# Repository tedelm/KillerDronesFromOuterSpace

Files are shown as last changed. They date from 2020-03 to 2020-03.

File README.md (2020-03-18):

# KillerDronesFromOuterSpace
</br>
Have you ever wanted to shot your friends and enemies with Nerf darts launched from a drone? 
</br>
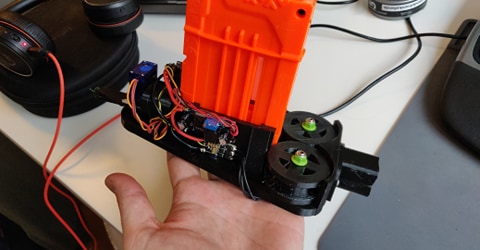
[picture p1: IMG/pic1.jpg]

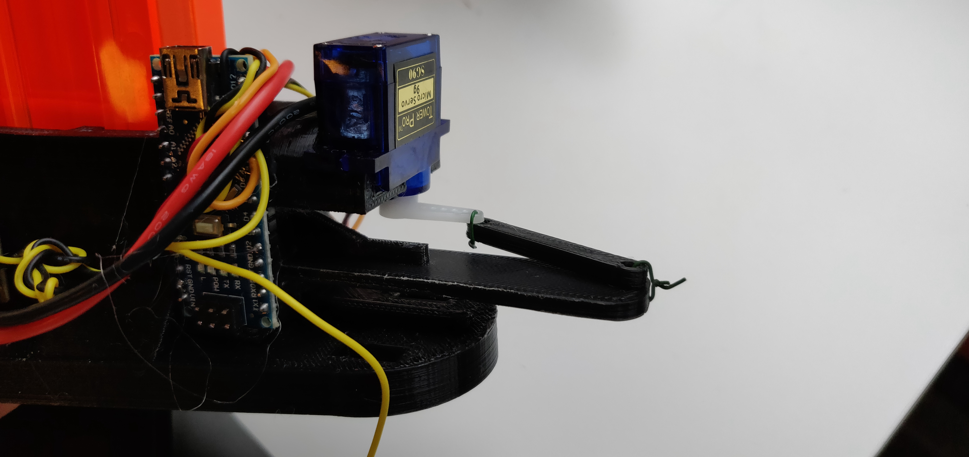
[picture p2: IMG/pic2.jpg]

</br>
</br>

# Make
Needed
- [ ]  Download KillerDroneFromOuterSpace files (Arduino and STL)
- [ ]  Download BLHeli Suite
- [ ]  Print STL files
- [ ]  1 x Nerf Mag.
- [ ]  2 x Blheli_s or Blheli_32 Esc (25-30amp)
- [ ]  2 x Brushless motor, like 2207 (6s 1600kv or 4s 2400kv)
- [ ]  1 x Arduino Nano
- [ ]  1 x SG90 Servo (9g servo)
- [ ]  1 x 5v BUCK/BEC (min 25v stepdown) like LM2596
- [ ]  1 x 4s/6s Lipo
- [ ]  3cm Thin (~1mm) Garden wire (for pulley/servo)
- [ ]  Super Glue
- [ ]  Some thin (~24AWG) and some thick(er) (~14) gauge wire
- [ ]  Some M3x6mm for motors (8pcs) and pipe (2pcs)
- [ ]  HotGlue Gun

# Flash BLHELI_S ESC´s
Download: <a href='http://www.mediafire.com/file/23jnmpa0kiqry1k/BLHeliSuite16714902.zip/file'>Windows BLHELI_S Suite</a></br>
or browse for your version: <a href='https://www.mediafire.com/folder/dx6kfaasyo24l/BLHeliSuite'>All versions</a></br>
</br>
1. Connect Arduino to Computer</br>
2. Start BLHeli Suite</br>
3. Options -> "Expert Mode"</br>
4. Make Interfaces</br>
5. Select "Port" eg. COM5</br>
6. Click Arduino BLHeli BootLoader</br>
7. After the arduino is flashed with blheli bootloader, disconnect the Arduino from computer.</br>
8. Select "ATMEL / SILABS interface" as described, its usually "SILABS BLHELI Bootloader (USB/COM)"</br>
9. Solder GND and Signal from ESC to Arduino GND and D2 and solder vbat+ and vbat- to ESC</br>
10. Connect Arduino to Computer and start BLHeli Suite, click "Connect"</br>
11. Connect Lipo (VBAT+/VBAT-)</br>
12. Click "Flash BLHeli", select newest FW (Default)</br>
13. Repeat steps 1-12 for both esc´s.</br>
</br>

# Flash BLHELI_32 ESC´s
Download <a href='http://www.mediafire.com/file/as2n6rkbah053zp/BLHeliSuite32_32711.zip/file'>Windows BLHELI_32 Suite</a></br>
or browse for your version: <a href='https://www.mediafire.com/folder/dx6kfaasyo24l/BLHeliSuite'>All versions</a></br>
1. Connect Arduino to Computer</br>
2. Start BLHeli Suite</br>
3. Options -> "Expert Mode"</br>
4. Make Interfaces</br>
5. Select "Port" eg. COM5</br>
6. Click Arduino BLHeli BootLoader</br>
7. After the arduino is flashed with blheli bootloader, disconnect the Arduino from computer.</br>
8. Select "ATMEL / SILABS interface" as described, its usually "SILABS BLHELI Bootloader (USB/COM)"</br>
9. Solder GND and Signal from ESC to Arduino GND and D2 and solder vbat+ and vbat- to ESC</br>
10. Connect Arduino to Computer and start BLHeli Suite, click "Connect"</br>
11. Connect Lipo (VBAT+/VBAT-)</br>
12. Click "Flash BLHeli", select newest FW (Default)</br>
13. Repeat steps 1-12 for both esc´s.</br>
</br>

# Flash Arduino
1. Download and istall Arduino IDE <a href='https://www.arduino.cc/en/main/software'>Link</a></br>
2. Open Arduino IDE and open the sketch "KillerDroneFromOuterSpace.ino" </br>
3. Select correct Arduino under </br>
    Tools->Board = Arduino nano </br>
    Tools->Processor = ATMega328p (Old bootloader)</br>
    Tools->Port = COMx</br>
4. Press "Upload"    </br>

# Connect to Arduino (schematic)
Schematic:</br>
    ESC #1 (signal) -> Arduino pin: D9</br>
    ESC #1 (gnd, for signal) -> Arduino pin GND  </br>
    ESC #2 (signal) -> Arduino pin: D10</br>
    ESC #2 (gnd, for signal) -> Arduino pin GND</br>
    Servo (signal)  -> Arduino pin: D8</br>
    Servo (gnd)  -> 5v BUCK/BEC GND out</br>
    Servo (Vcc/+)  -> 5v BUCK/BEC Vcc/+ out</br>
    RevoltOSD TX4 (Pin Toggle) -> Arduino pin: A7</br>
    5v Buck/BEC (IN GND/VCC) -> VBAT GND/VCC</br>

# Build
1. Test-fit everything</br>
2. File the parts that not fit perfect </br>
3. Super glue "Guider" to the "Bottom" </br>
4. Screw or glue the "pipe" to the "Bottom"
5. Test-fit the servo, see to it that the arm can move freely, connect slider and slider_arm to the servo with garden wire.
6. Super glue the servo in place.
7. Hotglue the electonics to the side :D

```code
```

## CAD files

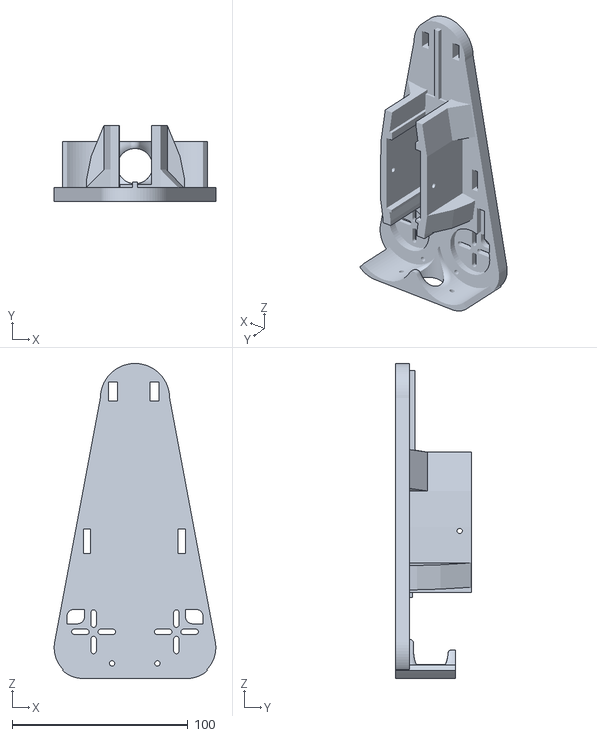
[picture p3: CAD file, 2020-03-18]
STL/bottom_v2.1.stl
91.9 x 43.0 x 179.0

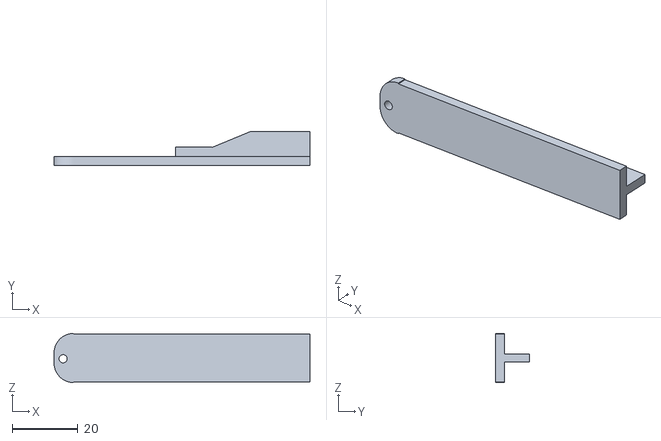
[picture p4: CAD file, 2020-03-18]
STL/slider2.1.stl
78.0 x 10.5 x 15.0

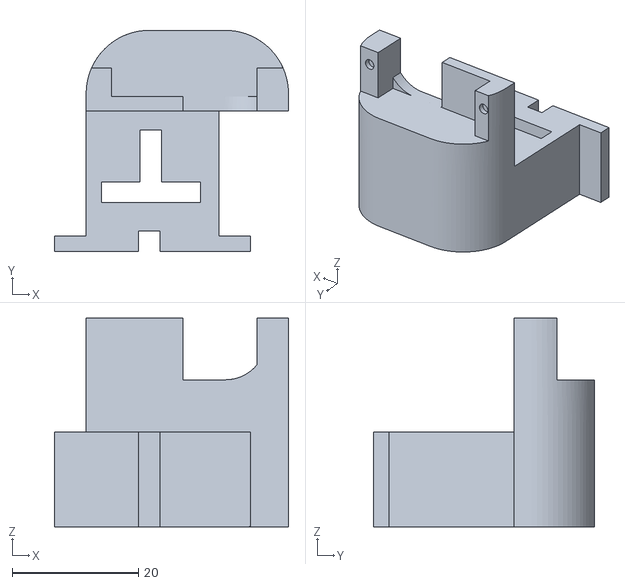
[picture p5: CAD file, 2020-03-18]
STL/Guider.stl
37.0 x 35.0 x 33.0

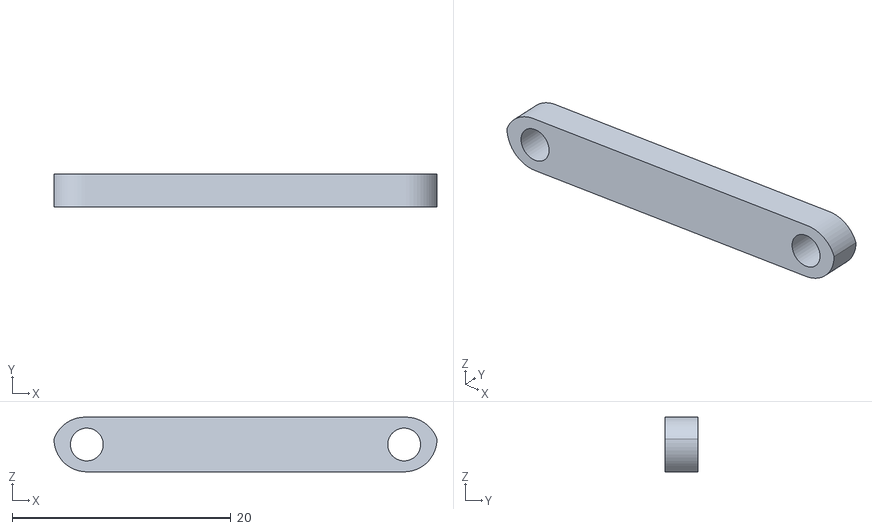
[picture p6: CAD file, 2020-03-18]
STL/slider_arm.stl
35.0 x 3.00 x 5.00

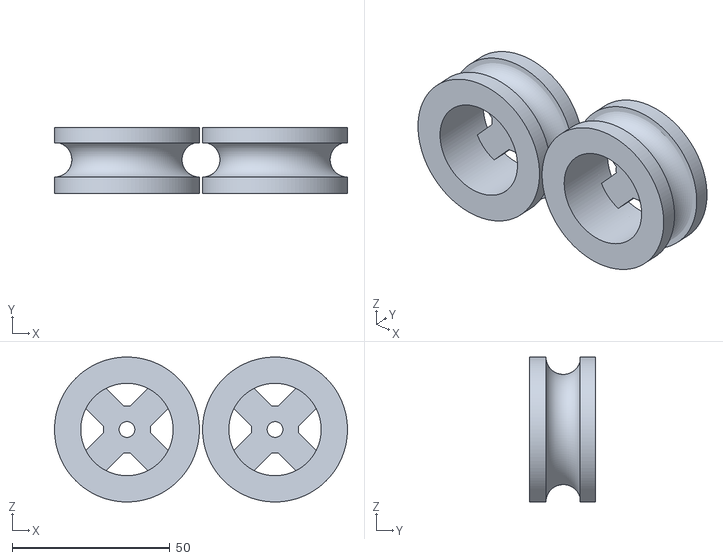
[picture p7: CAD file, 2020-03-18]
STL/driver_v2.stl
93.0 x 21.0 x 46.0

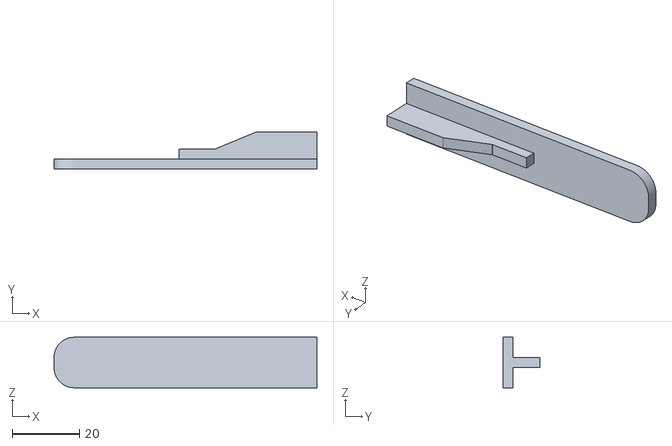
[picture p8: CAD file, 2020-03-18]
STL/slider.stl
78.0 x 11.0 x 15.0

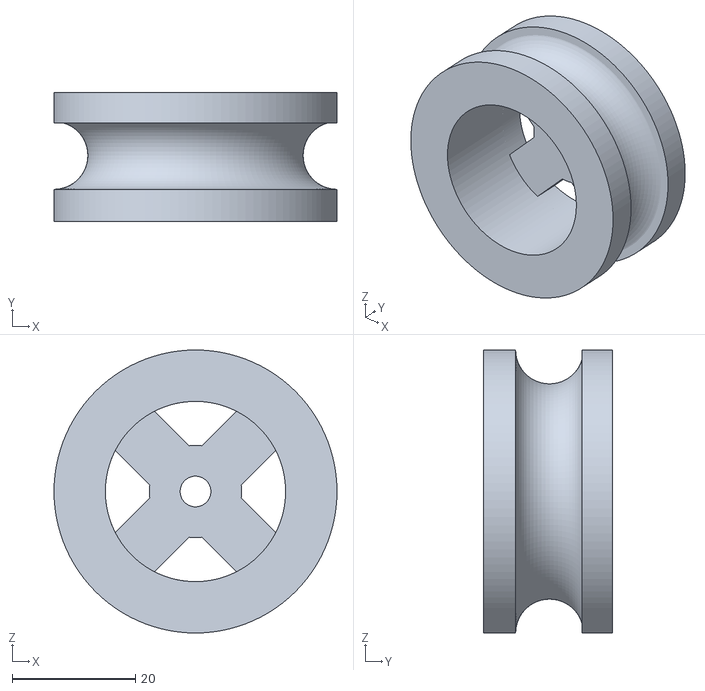
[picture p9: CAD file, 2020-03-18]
STL/driver_v2_1pcs.stl
46.0 x 21.0 x 46.0

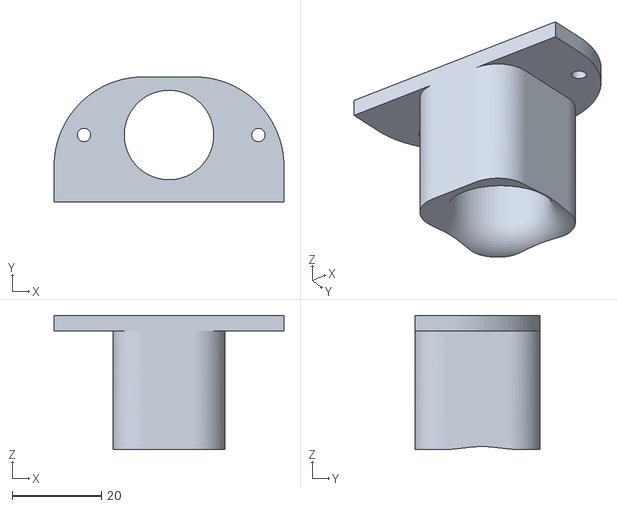
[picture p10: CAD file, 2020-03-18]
STL/pipe.stl
51.4 x 28.0 x 30.0

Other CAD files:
STL/bottom_v2.stl

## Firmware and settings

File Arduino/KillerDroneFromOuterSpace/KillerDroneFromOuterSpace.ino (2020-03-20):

//https://www.youtube.com/watch?time_continue=739&v=MvhqtOEihDg&feature=emb_title
//https://www.mediafire.com/folder/dx6kfaasyo24l/BLHeliSuite
//-> make interface -> Arduino BLHeli Bootloader


//Battery - > GND
//Trigger > D2
// Servo Signal (PULSE) > D9
// Servo Signal (PULSE) > D10

// Don't change the below setting 

#include <Servo.h>
Servo motor1;               //ESC1
Servo motor2;               //ESC2
Servo Feeder;               //Servo feeder
float motorMIN = 950;       //motor min, motors disabled
float motorMID = 1450;      //motor MID
float motorMAX = 1960;      //motor max
float MotorCMD = motorMIN;  //Command sent to esc
int motor1PIN = 9;          //Arduino PIN D9
int motor2PIN = 10;         //Arduino PIN D10
int TogglePIN = A7;          //A High/Low toggle pin on FC, RevoltOSD is TX4 3,3v. (1023/5)*3.3=675, so to be safe we set limit to 640
int TogglePINActive = 640;  //(1023/5)*3.3=675, so to be safe we set limit to 640
int FeederPin = 8;          //Servo
int TogglePINState = 0;     // variable to store the read value
int angle = 10;             //Servo angle
int ServoSteps = 25;             //Servo angle
int LastAction = 0;         //when button pressed
//

void setup() {
    Feeder.attach(FeederPin);           //Attach PIN
    motor1.attach(motor1PIN);           //Attach PIN
    motor2.attach(motor2PIN);           //Attach PIN
    Serial.begin(57600);                //Serial Monitor
    motor1.write(motorMIN);
    motor2.write(motorMIN);
    delay(5000);
}

void FeedDart(){
 // from 0 to 180 degrees
  for(angle = 10; angle < 180; angle = angle + ServoSteps){                                  
    Feeder.write(angle);               
    delay(5);                   
  } 
  // from 180 to 0 degrees
  for(angle = 180; angle > 10; angle = angle - ServoSteps){                                
    Feeder.write(angle);           
    delay(5);       
  } 
delay(250);
}

void EnableMotors(){

    if(LastAction == 0){
        //Ramp up motors MAX RPM
        for(MotorCMD = motorMIN; MotorCMD < motorMAX; MotorCMD = MotorCMD + 50){                                  
            Serial.println(MotorCMD);
            motor1.write(MotorCMD);
            motor2.write(MotorCMD);              
            delay(10);                   
        }

    }else{
        MotorCMD = motorMAX;
        Serial.println(MotorCMD);
        motor1.write(MotorCMD);
        motor2.write(MotorCMD);

    }
    
        MotorCMD = motorMAX;
        Serial.println(MotorCMD);
        motor1.write(MotorCMD);
        motor2.write(MotorCMD);
    LastAction = 1;
    
}

void DeactiveateMotors(){


        //Ramp down motors min RPM
        for(MotorCMD = motorMAX; MotorCMD > motorMIN; MotorCMD = MotorCMD - 10){                                  
            Serial.println(MotorCMD);
            motor1.write(MotorCMD);
            motor2.write(MotorCMD);
            delay(10);

            //Manual interrupt, check if button pressed while motors are spinning down
            ToggleState();

        }

    MotorCMD = motorMIN;        //Set motors MIN RPM
    Serial.println(MotorCMD);
    motor1.write(MotorCMD);
    motor2.write(MotorCMD);

    LastAction = 0;
}

void ToggleState(){
    
    TogglePINState = analogRead(TogglePIN);    //Read TogglePIN
    Serial.println(TogglePINState);
    
    if (TogglePINState > TogglePINActive){
        
        delay(50);
        TogglePINState = analogRead(TogglePIN);    //Read TogglePIN
        Serial.println(TogglePINState);
        //Doublecheck
        if (TogglePINState > TogglePINActive){

            //Check if motors already enabled
            if(LastAction == 1){
                FeedDart();     //Feed dart
            }else{
                EnableMotors(); //Start motors
                delay(25);     //sleep
                FeedDart();     //Feed dart
            }

            //Set last action to Enabled
            LastAction = 1;
        }
    
    }else{
      
      if(LastAction == 1){
        DeactiveateMotors(); //Start motors
        delay(25);          //sleep
      }
      
    }
}

void loop() {
    MotorCMD = motorMIN;
    //Check button
    ToggleState();
}
